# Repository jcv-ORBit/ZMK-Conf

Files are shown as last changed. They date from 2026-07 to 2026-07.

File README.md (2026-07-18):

# ORBit — capacitive-touch trackball bar · Build Guide (v7 / cap-touch)

Low bar trackball on the XIAO nRF52840 **Sense Plus** + PMW3610 stack.
Bearing cup, magnet scroll ring, haptics, and — new in this revision —
**capacitive touch buttons (CAP1188)** replacing every mechanical switch.
Footprint: 135.2 × 34.7 mm, unchanged. This README supersedes the v6 one;
the "Vessel — Build & Wiring Guide" artifact remains valid for assembly
steps A–C and E–H (its section D "Switches" is obsolete, see §4 here).

## What changed in the cap-touch revision

1. **All 6 micro-switches, the floor pockets, and the carrier bridge are
   GONE.** Buttons are now touch zones on the shell, sensed by a CAP1188
   8-channel module on the same I²C bus as the DRV2605L haptics.
2. **New tray: `ORBit_bottom_tray_captouch.3mf`** (drop-in — same walls,
   towers, cup, collar, battery bay, XIAO rails, LRA slot, hall towers):
   - switch pockets and carrier ledges removed; right floor is now a
     **CAP1188 bay**: 40.6 × 18.6 mm cavity (fits a 40 × 18 × 4 module),
     x 22.0–62.6, y ±9.3, 3 mm retaining fence, recessed 1.1 mm into the
     east wall, finger gaps mid-span for removal, wire notch at the west
     end pointing at the DRV/XIAO, two 0.6 mm ribs so solder joints
     don't rock the board.
   - the EC11 recess ribs (gear-route leftovers) are also deleted.
3. **Obsolete files** (keep for reference or delete):
   `ORBit_switch_carrier_left.3mf`, old `ORBit_bottom_tray.3mf`.
4. **Haptic click is now core, not optional.** With no mechanical
   tactility, the DRV2605L fires a click effect on every touch event.
5. **Audio is now provisioned** (piezo, or MAX98357A I²S amp + micro
   speaker on the free EXT pads) so the hardware is ready for the Phase-2
   voice assistant with no respin. See §1 BOM, §3 pin map, §5.6 roadmap.

### Why the device height is unchanged
The ball height is locked by PMW3610 optics — ball bottom ≈ z11 over the
lens at ≈ z9.2. The 6 mm 602040 cell sits floor (z2) to z8, well **under
the z16.2 wall rim**, as do the audio mounts (top z ≈ 9) and CAP bay — all
inside the existing envelope. Any real *slimming* (~2 mm) would come from
the tray-wall / shell-skirt overlap, but the shell, sleeve, ring, and
crown are a dialed-in mated set — a coordinated shell-source pass, not a
tray change.

---

## 1. Sourcing BOM (current build)

### Electronics
- **Seeed XIAO nRF52840 Sense Plus** ×2 (one device, one 2.4 G dongle)
- **PMW3610 breakout + lens** ×1 — mounts to `ORBit_sensor_sled`
- **CAP1188 8-key capacitive touch module** (~40 × 18 × 4 mm) ×1 — NEW
- **DRV2605L haptic driver** ×1 + **coin LRA** ×1 (LRA slot under XIAO)
- **Hall latches ×2** (scroll ring quadrature). TLE4946-2L or any
  **bipolar hall-effect LATCH** in a TO-92-style leaded package that
  runs at 3.3 V — easy subs: Honeywell **SS460S**, Allegro **A1221LUA**;
  TI **DRV5012** if you're OK with SMD (lowest power). Must be a
  *latch* (flips on alternating N/S), NOT a unipolar/omnipolar switch.
  Open-collector/open-drain outputs need the 10 kΩ pull-ups to 3V3
  (§ assembly artifact, step C).
- **Ø3×2 N52 discs** ×12 (ring) + ×8 (shell mount, 4 pairs)
- **LiPo NST 602040, 450 mAh / 1.67 Wh, 3.7 V** ×1 (on hand, **protected**)
  — 6 × 20 × 40 mm; the `_audio` tray pocket is sized for it. The chosen
  cell: already has its protection board (no add-on, no live-cell
  soldering), standard 3.7 V so the XIAO charges it **fully** at 4.2 V,
  1.5× the original runtime, and only 6 mm thick so it clears the rim with
  room to spare while adding moderate heft. *(Alternatives that also fit:
  TW312540 300 mAh thin cell; or the 122134 1000 mAh HV brute — but that
  one is unprotected + HV, so it needs an added PCM and only partly
  charges.)*
- **Slide switch** SS-13D07 ×1 — hard battery disconnect (shipping/storage/
  failsafe), inline on B+. Day-to-day power is IMU wake + soft-sleep;
  you'll rarely touch it. Shelf retained in the tray.
- **25 mm trackball** · **MR63ZZ bearings** ×3 + 3 mm filament axles
- Copper foil tape (~10 mm wide) + 30 AWG wire — touch electrodes
- **SK6812MINI-E addressable LEDs ×16** (+ spares; buy a strip/bag):
  6–8 halo ring + 6 zone windows + 2 slider — SK6812 runs on battery
  voltage, unlike 5 V WS2812. Plus `ORBit_led_diffuser`; translucent
  **smoke TPU** for the sleeve (it is the diffuser for all windows)

### Audio (voice feedback / chimes — provisions the assistant phasing)
Two tiers; wire whichever you want now — both fit existing void space, **no
new 3D files**. See §5.6 for what firmware drives them.
- **Tier 1 — piezo transducer** (chimes/alerts only): a Ø20–27 mm bare
  piezo disc, 0.5 mm thick (e.g. **CUI CPT-2065** or any Ø27 element).
  One PWM pin, no amp. Bonds flat to the shell roof interior; the shell
  becomes the diaphragm and radiates through the glow slots + seams.
- **Tier 2 — real voice** (recommended for the assistant): **MAX98357A**
  I²S DAC+class-D amp breakout (~16 × 13 mm) + one **8 Ω micro speaker**
  (15 mm round, ~4 mm thick — **CUI CMS-15113** / **PUI AS01508AO-3-R**;
  or an 11 × 15 mm rectangular cellphone speaker). The nRF52840 has **no
  DAC**, so this amp (or the piezo) is mandatory for any sound.
  - Wire both if unsure: the MAX98357A path supersedes the piezo. You can
    populate Tier 2 later and leave the pins unused until Phase-2 firmware.

### Fasteners
- M2×8 self-tapping ×2 (sled → posts) · M2×5 self-tapping ×4 (PMW3610 → sled)

## 2. Print plan
PETG, 0.2 mm layers. Parts: `ORBit_bottom_tray_captouch_audio`,
`ORBit_top_shell_captouch_glow`, `ORBit_sensor_sled`, `ORBit_crown` (redesigned),
`ORBit_scroll_ring_magnet`, `ORBit_base_skate`, `ORBit_tpu_top_sleeve` (TPU),
`ORBit_tpu_pad` (TPU), dongle case, tilt wedges/sidecar as desired.
Tray upright with paint-on supports only inside the sensor bay; shell
top-face-down on textured PEI; the CAP bay prints support-free (the 1.1 mm
wall recess bridges).

## 3. Wiring (XIAO Sense Plus — updated pin map)

| Pin | Net | Connect to |
|---|---|---|
| D0 | TOUCH_INT | CAP1188 ALERT/INT (was BTN_M1) |
| D1 | TOUCH_RST | CAP1188 RESET — optional, else tie high (was BTN_M2) |
| D2 / D3 | SCROLL_A/B | hall latch 1 / 2 OUT |
| D4 / D5 | SDA / SCL | **shared I²C bus: DRV2605L + CAP1188** |
| D6 | LED_DIN | SK6812 DIN (330–470 Ω in series) |
| D7–D10 | MOT / SCK / nCS / SDIO | PMW3610 (3-wire SPI) |
| 3V3 / GND | rails | PMW3610, DRV (+EN), CAP1188, halls, amp, pull-ups |
| B+ / B− | LiPo | slide switch inline on B+ (or EXT6 soft-off) |
| CS1–CS8 | touch zones | 30 AWG from CAP1188 to copper-foil electrodes |
| EXT1 | I2S_BCLK | MAX98357A BCLK (Tier-2 audio) |
| EXT2 | I2S_LRC | MAX98357A LRC / word-select |
| EXT3 | I2S_DIN | MAX98357A DIN |
| EXT4 | AMP_SD | MAX98357A SD (mute / power-save; tie high if unused) |
| —or— EXT1 | PIEZO | Tier-1 piezo (single PWM pin; other leg → GND) |

All D0–D10 through-holes are full; **audio lives on the 9 free EXT
castellated pads** (freed when the switch wiring was deleted). I²C
addresses don't collide (DRV2605L 0x5A, CAP1188 0x29 default). The
MAX98357A takes 3V3 (works to ~2.5 V, fine on battery); OUT± → 8 Ω
speaker. GAIN pin sets level — leave floating for 9 dB or strap per its
datasheet.

### Electrode layout (under the shell roof / button caps)
Cut ~10 × 14 mm copper foil pads, stick to the underside of each shell
button cap (the flexure caps stay — they're now cosmetic touch landmarks),
solder a 30 AWG lead to each, route down to the CAP1188 bay. Keep pads
≥4 mm apart. Suggested map: CS1 left-click · CS2 right-click · CS3 middle
· CS4 back · CS5 forward · CS6 push-to-talk · **CS7+CS8 swipe strip**
along the front roof edge (two elongated pads, interpolate for a slider)
— or gang CS7+CS8 as a proximity antenna (see §5).

## 4. Assembly deltas vs the Vessel artifact guide
Follow the artifact steps A–C and E–H unchanged. Replace step D with:
1. Drop the CAP1188 into the right-floor bay (fence retains it; ribs
   under the board). Wires exit the west notch toward the XIAO.
2. Foil electrodes on the shell (above), leads with ~20 mm slack so the
   shell still pops off.
3. Set touch sensitivity after closing up — the stack is shell (1.2 mm)
   + TPU sleeve; CAP1188 gain has plenty of range for that, tune
   SENSITIVITY and averaging registers with the sleeve fitted.

## 5. Firmware
### 5.1 Base (ZMK on nRF52840) — Phase 1
- Base: ZMK + community PMW3610 module; halls = quadrature encoder
  (`alps,ec11`, A/B on D2/D3, `steps = 6`).
- Touch: Zephyr ships a Microchip CAP12xx input driver — bind it on the
  I²C bus with INT on D0 and map 8 inputs to mouse buttons / behaviors
  (small devicetree + listener shim in ZMK).
- **Haptic click**: on any CS press event, fire DRV2605L effect 1
  (strong click); use a sharper/lighter effect per zone so left, right,
  and PTT each *feel* different. Fire on press, not release, <10 ms.
- PTT / talk-to-text: hold CS6 → send the OS dictation hotkey (easy
  path); onboard PDM mic streaming over USB/BLE audio is the advanced
  custom-firmware path.
- Wake: IMU wake-on-motion interrupt from soft-off + CAP1188 proximity
  wake (it can run in a low-power cycled mode and interrupt on approach).

### BLE profiles, pairing, device switching
- ZMK keeps **5 BLE profiles** and auto-reconnects to the last active one
  on wake (IMU wake-on-motion → reconnect in ~1–2 s; approach-glow masks it).
- **Switch hosts**: bind `&bt BT_SEL n` / `BT_NXT` to a combo —
  recommended gesture: *touch-hold the slider (CS7/8) + spin the crown*;
  each detent steps a profile, halo blinks the profile number in amber,
  haptic tick per step.
- **Pair a new device**: select an empty profile — the device advertises
  automatically and appears in the host's Bluetooth list. Long-hold the
  same gesture = `&bt BT_CLR` (forget current profile).
- **Dongle** (2nd XIAO): a BLE→USB HID receiver for hosts with no/locked
  Bluetooth or for lowest latency. It is optional and is NOT storage —
  it enumerates as a plain USB mouse. It occupies one of the 5 profiles;
  moving the dongle between machines is itself a host-switching story.

### Ambient glow architecture (dark slate / copper-bronze accent)
Goal: soft warm amber (logo palette) halo around the ball, a dot per
touch zone, and a light-line along the slider. Subtle, breathe-on-approach,
off in sleep.
- **Driver**: preferred = the existing D6 addressable chain — use
  **SK6812MINI** (happy at 3.3–3.7 V on battery, unlike 5 V WS2812):
  6–8 LEDs in a ring under the aperture boss + 1 under each button
  window + 2 under the slider pinstripe ≈ 10–12 LEDs, one pin, exact
  copper-amber set in firmware. Alternative: the CAP1188 has 8 LED
  driver pins with hardware touch-linking and breathe/pulse behaviors
  (zero firmware) — but only if your module breaks LED1–8 out; most
  generic ones don't. Check the header before counting on it.
- **Ball halo needs no cutting**: light fired upward under the aperture
  boss leaks through the existing shell-aperture / ring-skirt shadow gap.
- **Button + slider windows — CUT, in `ORBit_top_shell_captouch_glow.3mf`**:
  0.8 mm through-slots at |y| = 13.9 (a third "light seam" running just
  outboard of the twin pinstripes). Zone windows (6 mm long) on one roof
  edge at x = **−38, −27** (back / fwd), **25** (PTT), **44, 52, 60**
  (L / M / R click); an 18 mm **slider window at x 41–59** on the
  opposite edge, directly above the CAP1188 bay. The windows *define*
  the touch zones — stick each foil electrode under the roof beside its
  window, LED under the slot. The six switch **stems are deleted** from
  this shell (nothing to press anymore); the flexure caps and hinges are
  kept as tactile landmarks. Sleeve stays **uncut** — print it in
  translucent smoke TPU: sealed against dust, diffuses the glow,
  invisible until lit.
- **HiLetgo module L1–L8 pins**: use them on the bench (hardware
  touch-linking while tuning sensitivity), not in the final glow — the
  SK6812 chain does color, blink-counts, and animations that the L-pins
  can't.
- **Power**: amber at low duty, breathing only on proximity/touch, all
  off in soft-sleep — negligible against the 300 mAh cell with
  wake-on-motion.

### Audio placement — integral mounts in the `_audio` tray
The tray carries the Tier-2 audio mounts over the CAP1188 bay (the only
place with vertical void):
- **MAX98357A amp**: recessed shelf over the CAP bay's **west/inner end**
  (x 22.5–35, seat z 5.8), non-magnetic so its nearness to the hall
  towers is harmless. Wires drop out the open east side to the CAP bundle.
- **Speaker**: an up-firing corral over the CAP bay's **east end**
  (x 45–59, seat z 5.6), aimed at the 18 mm slider glow window as its
  acoustic port (through the smoke TPU). Placed as far from the scroll
  **hall latches** as the bay allows — nearest-corner gap ≈ 13 mm.
  ⚠ A speaker has a magnet: if you see phantom scroll, that coupling is
  why — add a thin steel shield washer behind the speaker, or shift it
  east a few mm. Use the **thin 11 × 15 × 3.5 mm** rectangular speaker
  here (fits the corral and the roof); a 15 mm round also drops in.
- **Assembly order**: wire the CAP1188 first, then set the amp and speaker
  into their mounts (they sit just above the module). Dry-fit before
  bonding.
- **Piezo alternative** (Tier 1): skip both mounts, bond a Ø27 disc to the
  shell roof — sound exits the glow slots. One PWM pin, no amp.
- **Power**: chimes are free; class-D voice is bursty (100s of mA peaks) —
  the 1000 mAh cell handles short prompts easily, not continuous playback.

### Onboard storage ("carry your config")
- The XIAO nRF52840 has **2 MB QSPI flash**; TinyUSB MSC can expose it
  as a small USB drive over USB-C (wired only — BLE cannot serve files).
- Recommended product shape: **the device carries its own keymap/macros/
  settings as editable text files** — plug into any machine, tweak, done,
  no companion app. Do NOT pitch it as a file-shuttle: 2 MB is tiny, and
  a pointing device that also enumerates as removable storage pattern-
  matches BadUSB to corporate IT. Gigabyte storage would need a microSD
  on spare EXT pads (SPI) — judged overdesign; skip.

### 5.6 Firmware roadmap — the adaptation assistant (phasing)
The hardware above is fully provisioned for a voice + haptic "device
adaptation assistant." Build it in phases so the firmware ambition never
blocks the physical product — the same PCB stack runs all three.

**Phase 1 — ship on ZMK (now).** §5.1–§5 above: pointer, touch buttons,
haptic click, glow, per-profile BLE switching, IMU wake. A real, usable
trackball today. Validate the object.

**Phase 2 — custom Zephyr assistant.** ZMK *is* Zephyr underneath; drop to
raw Zephyr when the assistant features need audio + custom BLE + sensor
fusion (ZMK's abstractions fight all three). Buildable, genuinely
distinctive:
- **Voice feedback = pre-rendered clip library in the 2 MB QSPI flash**,
  played over I²S (Tier-2 amp). A finite prompt set ("switched to
  laptop," "precision on," "hold to talk") — how earbuds/cameras do voice.
  The nRF **cannot** synthesize arbitrary speech on-device; arbitrary TTS
  is a host job (host renders → streams over **USB Audio Class**, which
  also carries the PDM mic → the puck becomes a little speakerphone).
- **Personalization = an adaptive rules/stats engine, not an LLM.** Counters,
  timers, per-app config recall — deterministic, tiny, debuggable. "Learns
  your favorite config per host and announces the switch (voice + haptic +
  glow)" is the shippable core.
- **TinyML where it earns it:** two small models only — keyword spotting
  (a few voice commands) and IMU **gesture** classification. TFLite-Micro /
  Edge Impulse territory on the M4F.
- **Device switching by gesture (relative, reliable):** tilt/rotate the
  puck one way → host 1, the other way → host 2. Uses tilt-relative-to-
  gravity; rock-solid with the 6-axis IMU.

**Phase 3 — research spikes (defer).**
- **True spatial "point at the device" switching** is NOT possible with the
  6-axis IMU: accel gives tilt-vs-gravity, gyro drifts, and there's **no
  magnetometer** for absolute heading. It needs a 9-axis board (+ calibration
  ritual) or BLE AoA silicon (nRF5340-class). Use relative gesture switching
  (Phase 2) until/unless a 9-axis respin happens.
- On-device behavioral "AI" beyond the rules engine → host/cloud, not the M4F.

## 6. Feature roadmap ("over the edge" list, all zero/near-zero BOM)
1. **Solid-state buttons + per-zone haptic click** — the headline. No
   switch wear, sealed top, tunable feel.
2. **Swipe strip** (spare CS7/CS8): horizontal scroll, volume, or tab
   switcher. A trackball with a touch slider is a genuine differentiator.
3. **Approach glow + ambient accent lighting**: proximity mode + the
   amber glow architecture above — halo, zone dots, slider line breathe
   before your hand lands; radio wakes at the same moment (hides BLE
   reconnect latency).
4. **Precision / jog mode**: touch-hold a zone while rolling the ball →
   CPI drops 4×; hold + ring spin = per-app jog dial.
5. **PTT / talk-to-text** via onboard mic (CS6 zone) — already planned.
6. **IMU gestures**: wake-on-motion (planned), lift-to-lock (cursor
   freezes when you reposition the unit), tilt-to-switch hosts,
   double-tap the shell as a hidden button.
7. **Voice + haptic assistant** (Phase 2, §5.6): announced host switches,
   spoken onboarding/coaching from a clip library, keyword commands.
8. Deliberately *not* included: touch typing zones, RGB theatrics,
   displays, on-device TTS, absolute spatial awareness — they'd dilute the
   "quiet desk object" identity or over-reach the M4F/6-axis hardware.

## 7. File manifest (current)
| File | Status |
|---|---|
| `ORBit_bottom_tray_captouch_audio.3mf` | **CURRENT tray** — cap-touch + 602040 (450 mAh protected) battery pocket + integral amp/speaker mounts |
| `ORBit_bottom_tray_captouch.3mf` | superseded (cap-touch, old 300 mAh bay, no audio mounts) |
| `ORBit_bottom_tray.3mf` | superseded (switch version) |
| `ORBit_top_shell_captouch_glow.3mf` | **current shell** — glow windows cut, switch stems removed |
| `ORBit_top_shell_detailed.3mf` | ⚠ DO NOT SLICE — contains 7 stacked copies plus a misplaced collar chimney and a solid Ø22 plug at the origin (WIP leftovers) that would block the ball bore |
| `ORBit_tpu_top_sleeve.stl` / `ORBit_crown.stl` | current finish parts |
| `ORBit_scroll_ring_magnet` / `ORBit_sensor_sled` / `ORBit_base_skate` | unchanged |
| `ORBit_switch_carrier_left.3mf` | **obsolete** |
| `ORBit_all_files.3mf` | re-plate: swap in the captouch tray, drop the carrier |
| dongle case, LED diffuser, tilt wedges, sidecar, TPU pad | unchanged |

**Audio needs no 3D files** — piezo bonds to the shell roof; Tier-2
speaker + MAX98357A occupy existing void (§ Audio placement). Both are
retrofittable at any time.

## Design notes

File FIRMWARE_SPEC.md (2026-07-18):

# ORBit Firmware Specification — rev A (2026-07-17)

Handoff spec for firmware development on the ORBit capacitive-touch trackball bar.
Hardware and geometry are FROZEN at this revision. The wiring section of the project
README (v7 cap-touch) is authoritative for harness details; this file is authoritative
for firmware scope and contracts.

## 1. Device summary

Low-profile wireless trackball bar, 135.2 × 34.7 × ~19 mm (138 × 37.5 with TPU sleeve),
XIAO nRF52840 Sense Plus. No moving switches: optical trackball, magnetic scroll ring
(hall quadrature), 6 capacitive touch zones, 2-pad capacitive slider. Outputs: 8-LED
amber glow chain, LRA haptics, I2S speaker. Identity: quiet dark desk object — amber
light only, subtle haptics, sound opt-in. Every feature must work with the sleeve fitted.

## 2. Platform + pin map (authoritative)

| Pin | Net | Device |
|---|---|---|
| D0 | TOUCH_INT | CAP1188 ALERT |
| D1 | TOUCH_RST | CAP1188 RESET (or tie high) |
| D2 / D3 | SCROLL_A/B | hall latches SS460S (quadrature, 10k pull-ups to 3V3 on harness) |
| D4 / D5 | SDA / SCL | shared I2C: CAP1188 @0x29, DRV2605L @0x5A |
| D6 | LED_DIN | SK6812MINI-E chain ×8 (330–470 Ω series; battery-voltage strip, 3.3 V logic OK) |
| D7 | MOT | PMW3610 motion IRQ |
| D8 / D9 / D10 | SCK / nCS / SDIO | PMW3610 3-wire SPI (park MISO on unused pin; reads on SDIO) |
| EXT1 / EXT2 / EXT3 | I2S BCLK / LRC / DIN | MAX98357A |
| EXT4 | AMP_SD | MAX98357A shutdown (drive low when idle) |
| B+ / B− | LiPo 602040 450 mAh protected | hard slide switch inline on B+ |

Sensor board: randware/siderakb PMW3610 breakout (23.5 x 31.5 x 1.6, optical center =
board center, M3 holes on a 17.5 x 25.5 grid). Mounted component-side down on the v2
sled; lens reference plane at device z8.6, Z = 2.4 mm to the ball (datasheet 2.2-2.6).

Onboard (XIAO Sense): LSM6DS3TR-C 6-axis IMU (internal I2C, wake-on-motion), PDM mic,
2 MB QSPI flash (P25Q16H), USB-C, LiPo charger (4.2 V). No DAC (all audio via I2S amp).
No magnetometer (tilt-relative gestures only; absolute heading impossible).

## 3. Physical → firmware map

Coordinates: device mm; x −67.6 (west/USB) … +67.6 (east); y −17.35 (front, glow-dot
edge) … +17.35 (rear, slider edge).

| Surface | Physical | Firmware contract |
|---|---|---|
| Trackball | Ø25 ball at z11, PMW3610 lens ref plane z8.6 (Z=2.4 to ball, datasheet 2.2–2.6) | REL X/Y, CPI 600 default; set swap/invert flags at bring-up (board mounts component-side down, long axis = device x) |
| Crown | Ø33.8 ring, 12 alternating magnets, halls at (6.2,14.35)/(11.75,14.35) | quadrature 24 edges/rev; continuous scroll |
| Touch zones | foil electrodes under shell caps; finger stack = 1.0 mm TPU + 1.2 mm shell | CS1 L-click (x38.6–50) · CS2 R-click (x51.5–65 rear) · CS3 M-click (x51.5–65 front) · CS4 back (−48…−28) · CS5 fwd (−26…−8) · CS6 PTT (25.7–37). Act on press <10 ms with haptic |
| Slider | CS7+CS8 elongated pads, rear edge x41–59 | v1: half-strip taps (vol/scroll, both=mute); v2: interpolated absolute position |
| Glow | 8× SK6812 in shell pockets w/ funnels → sleeve lenses | index 0–5 = zone dots WEST→EAST (positionally over CS4,CS5,CS6,CS1,CS3,CS2), 6–7 = slider (x45.5/54.5). Amber #FFB457 family ONLY; ≤30% on battery; off in sleep |
| Haptics | LRA Ø10×4 at (−52,0), DRV2605L | per-zone effect identity: sharp click L/R, soft tick back/fwd, double-tick PTT, micro-tick per scroll/profile step. Run LRA auto-cal once, persist |
| Speaker | 15×11 8Ω 0.7W in deck (50.5,−6.5), floor vent | I2S 16-bit mono clips from QSPI; chimes ≤1 s, prompts ≤3 s; AMP_SD low when idle |
| USB | port high on west wall through sleeve window | charge + HID; later MSC/CDC/UAC composite |
| IMU | west end, board component-side down | wake-on-motion = sleep exit; lift-to-lock; double-tap; tilt-hold gestures |

Hardware gotchas that masquerade as firmware bugs:
- Speaker magnet is 15.3 mm from nearest hall latch → phantom scroll during audio = magnetic coupling (hardware fix), not code.
- Cap-sense MUST be tuned with the TPU sleeve fitted (dielectric stack roughly halves raw counts vs bare bench).

## 4. v1 launch firmware (ZMK) — current state and work package

Repo seed: `zmk-config/` — shield `vessel` on `seeeduino_xiao_ble`, GitHub Actions build,
badjeff `zmk-pmw3610-driver` module. Working: PMW3610 pointer (SPI1, MOT D7, CPI 600),
halls as `alps,ec11` steps=24 (bound to volume as placeholder), deep sleep 30 min, BLE +8 dBm.

**CRITICAL: the config predates the cap-touch pivot.** D0/D1 are still direct-GPIO buttons
(`kscan_direct` + 2-key keymap). The v1 work package:

1. Delete `kscan_direct` and the 2-key keymap (D0/D1 now belong to CAP1188).
2. Bring up CAP1188: Zephyr `microchip,cap12xx` input driver on I2C0 @0x29, INT on D0;
   thin listener mapping press/release → ZMK behaviors. Fallback if the driver fights
   ZMK's input pipeline: small custom module (ALERT pin + status registers).
3. Zone map per §3 (CS1→LCLK … CS6→PTT-as-dictation-hotkey-hold).
4. Slider v1: CS7=scroll-left/vol-down, CS8=scroll-right/vol-up, both=mute.
5. Haptic module (no ZMK driver exists): DRV2605L init + auto-cal at boot (persist),
   library effect per CS press; touch→haptic <10 ms.
6. Glow v1 on D6 (`worldsemi,ws2812-spi` compatible works for SK6812): amber idle low
   duty, zone flash on touch, breathe on proximity wake, all-off in sleep. No animations.
7. Wake: IMU wake-on-motion + CAP1188 standby-cycled proximity; glow breathe masks BLE
   reconnect (1–2 s).
8. Profiles: ZMK 5-profile BLE; gesture = touch-hold slider + crown spin steps profiles
   (haptic tick per step, LED0–4 blink index); long-hold = BT_CLR.
9. Rebind crown to true wheel scroll (`&msc`); slider owns volume.
10. Stretch: `vessel_dongle` shield (2nd XIAO as BLE-central→USB-HID bridge).

**v1 definition of done:** pair to two hosts + gesture-switch between them; ball/ring/
6 zones/slider all functional with per-zone haptics; approach glow; soft-sleep <50 µA
target, active <5 mA avg with glow at duty (30-day standby on 450 mAh); survives sleeve
on/off without retune (auto-recal on wake).

## 5. Phase 2 — custom Zephyr (product vision)

Drop from ZMK to raw Zephyr when audio + custom BLE + sensor fusion are in scope.
Architecture: input service (PMW3610/CAP/halls/IMU) → interaction engine (gestures,
slider interpolation, chords) → deterministic policy/rules engine (per-host+per-app
profiles, counters — NOT an LLM) → outputs (glow scenes, haptic grammar, I2S clip
player) + transports (BLE HID+BAS+custom ORBit GATT config service; USB composite
HID+MSC+CDC, later UAC; littlefs on QSPI).

Commitments: continuous slider w/ LED position feedback; precision mode (hold zone →
CPI÷4) and jog (hold + crown); voice clip library in QSPI (nRF cannot TTS — arbitrary
speech is host-rendered over USB Audio when docked); consistent haptic vocabulary;
IMU lift-to-lock / double-tap / tilt-hold host switch; config-as-files over opt-in USB
MSC (hold CS6 while plugging — BadUSB-perception mitigation); ORBit GATT service
mirroring config; TinyML capped at exactly two models (PDM keyword spotting, IMU
gesture classification; TFLite-Micro).

## 6. Phase 3+ / adjacent

- Mission deck: powered SBC dock (Pi Zero 2 W class) scripting the device over USB
  composite + versioned CDC command channel — keep descriptors clean now.
- DFU: stock UF2 (double-tap reset) for v1 → MCUboot signed BLE DFU in Phase 2
  (sleeve-off access must never be required for updates).
- Absolute "point-at-machine" switching: impossible on 6-axis (no heading ref) — needs
  9-axis respin or BLE AoA. Deferred; tilt-relative covers it.
- Battery: voltage-curve fuel gauge → BLE BAS + crown-hold charge meter on LED0–5.
- Manufacturing test mode: hidden build target exercising every subsystem (LED walk,
  haptic sweep, tone, sensor dumps over CDC). Build it in Phase 1.

## 7. Working agreements

- Bring-up order (hardware-risk order): pointer direction → ring steps → CAP sensitivity
  (sleeve fitted) → haptic autocal → glow chain → sleep/wake → profiles → audio.
- Keep the ZMK shield for v1; Phase 2 lives in a sibling Zephyr app sharing devicetree
  fragments.
- Identity guardrails: amber-family light only, no RGB theatrics; subtle haptics; sound
  off by default; every feature works sleeve-on.
- The CAD is parametric Python — if firmware needs a physical change (LED position,
  access hole), it is a one-line edit and a reprint. Ask; don't work around.

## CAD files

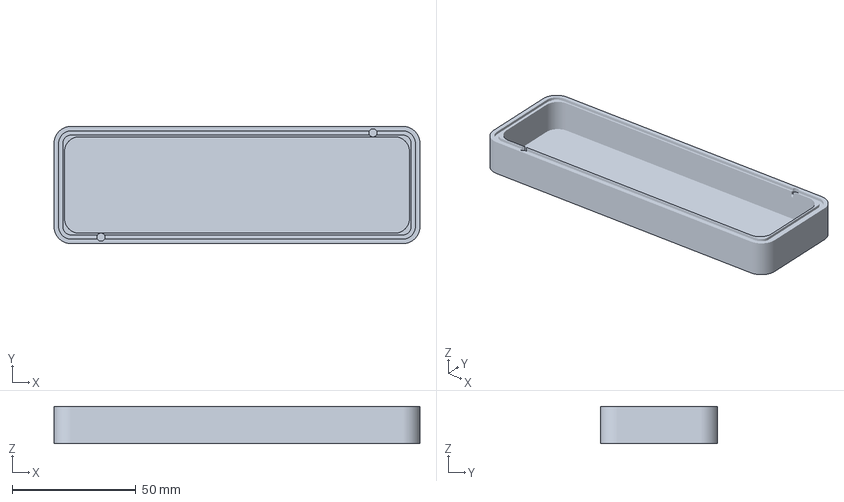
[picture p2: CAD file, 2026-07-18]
ORBit_case_lid.3mf
148.0 x 47.5 x 15.0 mm

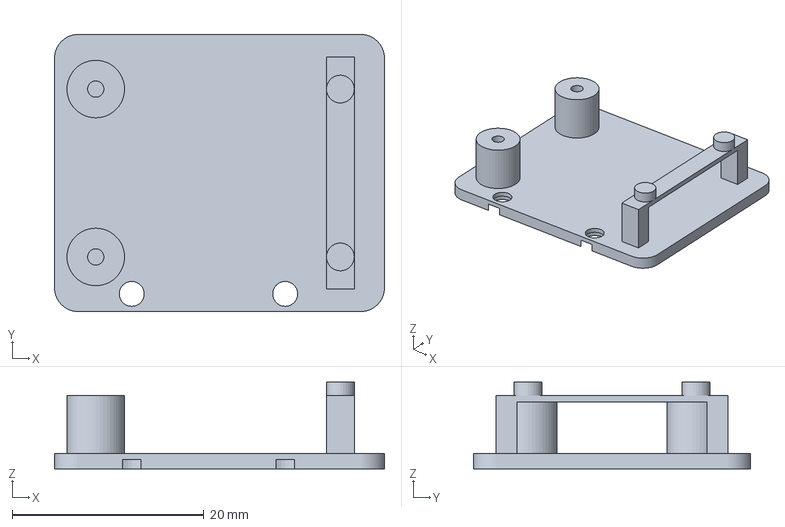
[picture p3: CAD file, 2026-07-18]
ORBit_sensor_sled_v2_pmw.3mf
34.4 x 28.9 x 9.05 mm

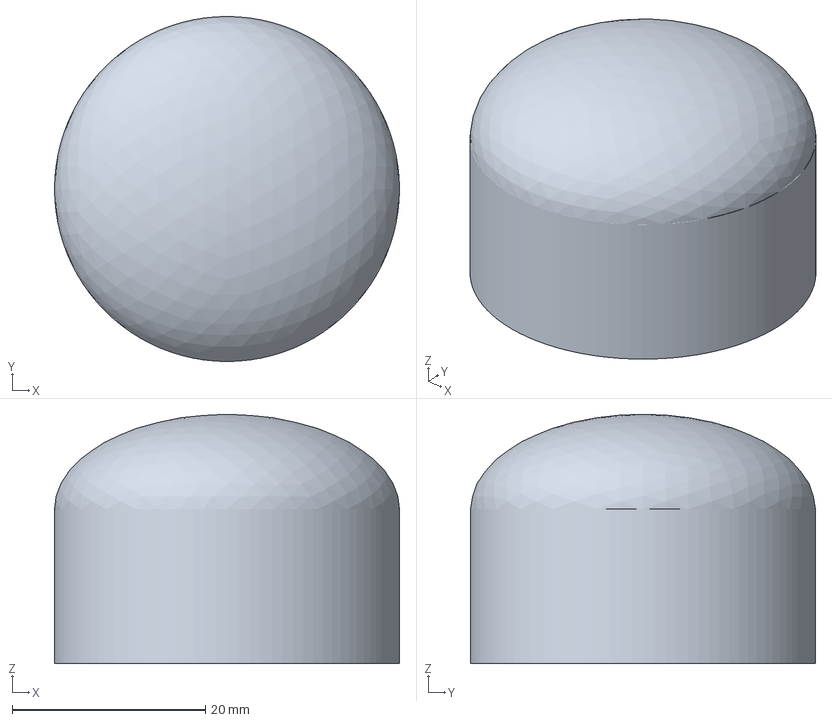
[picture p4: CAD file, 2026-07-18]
ORBit_ball_garage.3mf
35.7 x 35.7 x 25.8 mm

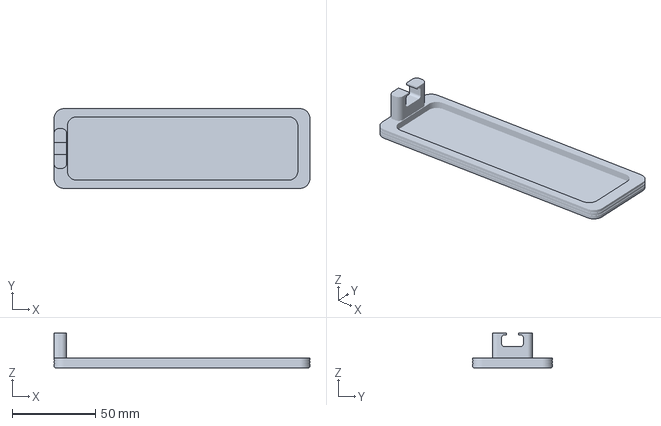
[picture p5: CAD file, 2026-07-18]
ORBit_launch_pad.3mf
154.0 x 48.0 x 21.0 mm

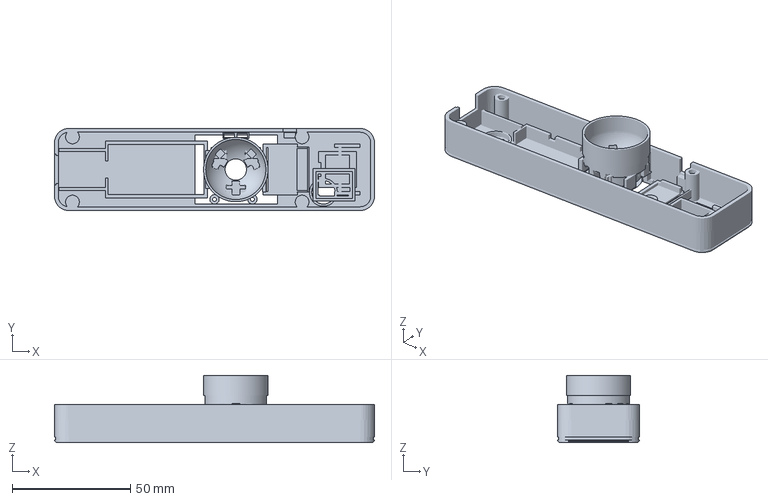
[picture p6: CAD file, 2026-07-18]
ORBit_bottom_tray_v4_pmw.3mf
135.2 x 34.7 x 28.4 mm

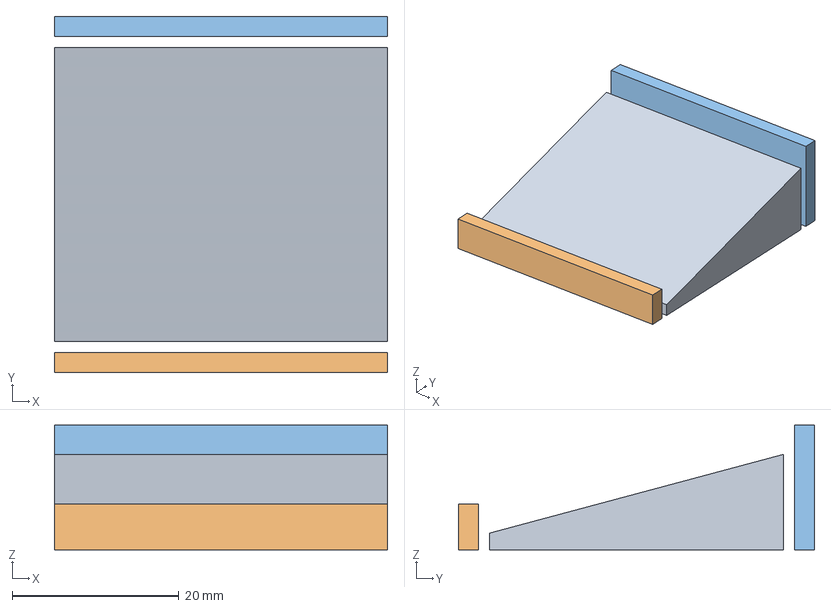
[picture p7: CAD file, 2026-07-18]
ORBit_tilt_wedge_15deg_v2.3mf
40.0 x 42.7 x 15.0 mm

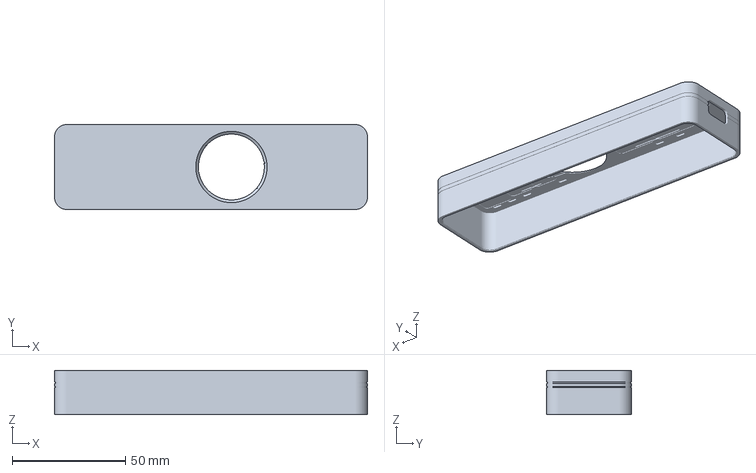
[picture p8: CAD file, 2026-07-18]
ORBit_tpu_top_sleeve_v2.3mf
138.0 x 37.5 x 19.4 mm

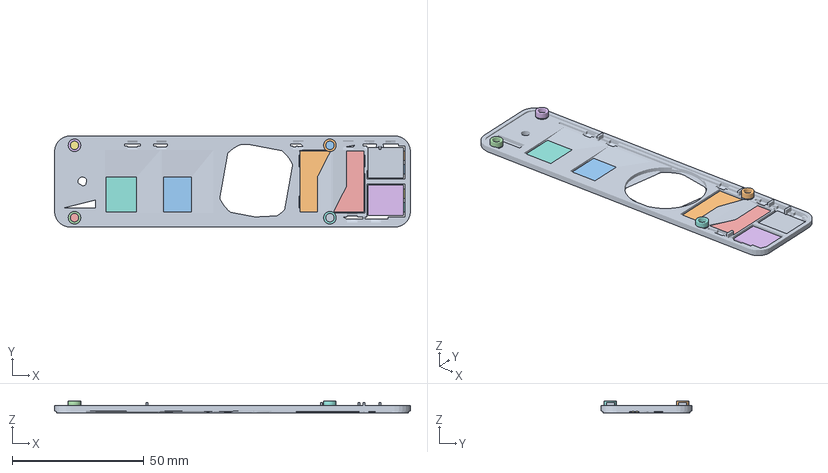
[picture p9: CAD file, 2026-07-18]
ORBit_top_shell_v3_x2d.3mf
135.2 x 34.7 x 4.60 mm
shell_main_v3

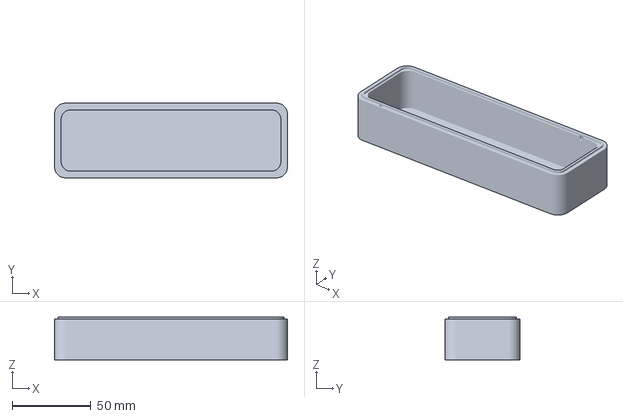
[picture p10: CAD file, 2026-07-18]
ORBit_case_base.3mf
148.0 x 47.5 x 27.2 mm

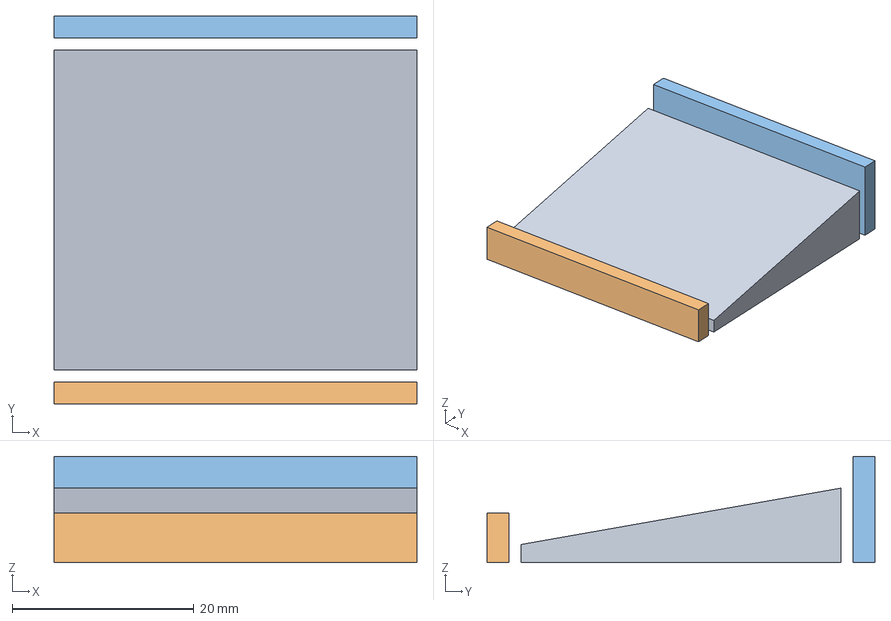
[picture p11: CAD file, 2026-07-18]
ORBit_tilt_wedge_10deg_v2.3mf
40.0 x 42.7 x 11.7 mm

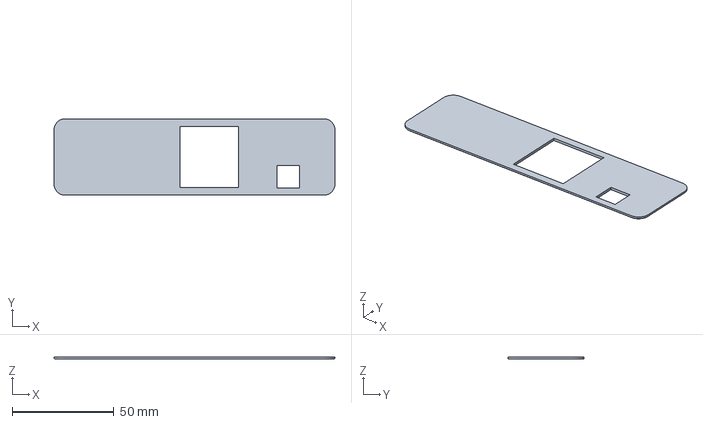
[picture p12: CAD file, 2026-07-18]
ORBit_base_skate_v2.3mf
138.0 x 37.5 x 1.20 mm

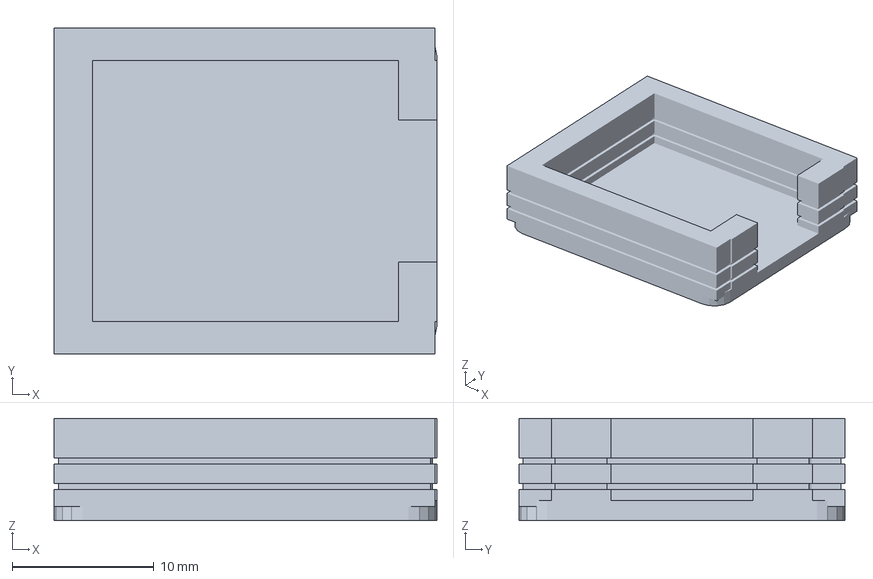
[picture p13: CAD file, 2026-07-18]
ORBit_dongle_case_base_v2.3mf
27.0 x 23.0 x 7.20 mm

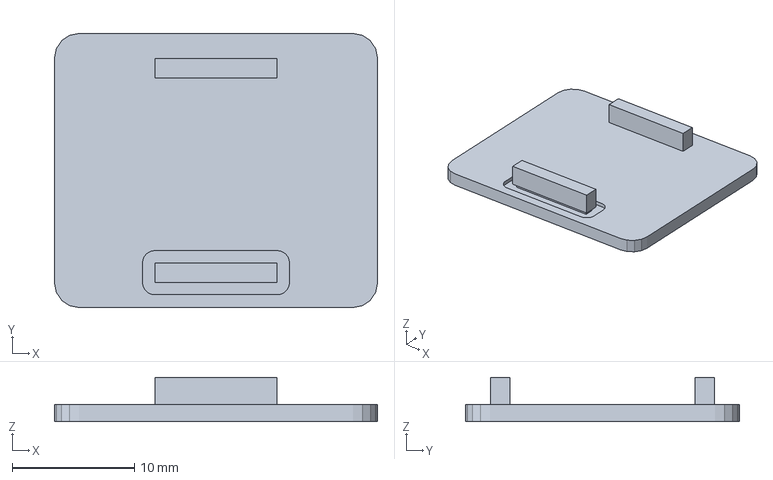
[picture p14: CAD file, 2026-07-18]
ORBit_dongle_case_lid_v2.3mf
26.4 x 22.4 x 3.60 mm

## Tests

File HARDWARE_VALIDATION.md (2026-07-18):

# ORBit — Hardware Validation Checklist

Every value in the v1 firmware that can only be confirmed on the physical device
lands here, with the **exact expected behavior** and **how to adjust** it. The
firmware ships a best-documented default plus a marked tuning point (Kconfig
option or devicetree property) for each; this file is where a human closes the
loop with hardware in hand.

- **No hardware was in the loop** when this firmware was written. Treat every
  unchecked box as unverified, not as broken.
- Tune in **bring-up order** (spec §7, hardware-risk order): pointer direction →
  ring steps → CAP sensitivity (sleeve fitted) → haptic autocal → glow chain →
  sleep/wake → profiles → audio.
- **Cap-sense and glow diffusion must be tuned with the TPU sleeve fitted** — the
  dielectric stack roughly halves raw touch counts vs. a bare bench (spec §3).
- The manufacturing **test mode** build (spec §6: LED walk, haptic sweep, tone,
  sensor dumps over CDC) is the intended harness for running this checklist. It
  is built in Phase 1; see its section below once it lands.

This checklist grows as each work-package PR merges. Items are added by the PR
that introduces the tunable.

---

## Legend
- **Observe** — what to do / watch on the device.
- **Expected** — the pass condition.
- **Tune** — the firmware knob to change if it's wrong, and where it lives.

---

## 1. Trackball pointer direction & CPI  _(seed; PMW3610)_
- [ ] **Observe:** move the ball up/down/left/right; watch the cursor.
- **Expected:** cursor tracks 1:1 in the same direction on all four axes.
- **Tune:** the board mounts **component-side down, long axis = device x**
  (spec §3), so at least one invert/swap is likely needed. Uncomment/adjust in
  `zmk-config/config/boards/shields/vessel/vessel.overlay` on the `trackball`
  node: `swap-xy;`, `invert-x;`, `invert-y;`.
- [ ] **Observe:** general tracking speed/feel at the default **CPI 600**.
- **Expected:** comfortable desktop tracking; no skipping.
- **Tune:** `cpi = <600>;` on the same node (datasheet Z = 2.2–2.6 mm; lens ref
  plane sits at Z = 2.4 to the ball — mechanical, not firmware).
- **Note:** the PMW3610 runs on **SPIM3** (not SPIM1) — SPIM1 and the CAP1188's
  I²C (TWIM1) are the same nRF52840 instance and can't coexist. Same pins
  (D8/D9/D10); if the pointer is dead after the item-2 change, suspect the SPI3
  move first.

## 2. Scroll ring (hall quadrature) step feel  _(seed)_
- [ ] **Observe:** spin the crown; count detents vs. scroll/volume steps.
- **Expected:** smooth, continuous stepping; direction matches spin.
- **Tune:** `steps = <24>;` on the `scroll` (`alps,ec11`) node in the overlay.
  > Note: spec §3/§4 say **24 edges/rev** (authoritative); the project README
  > §5.1 says `steps = 6`. Per precedence the firmware uses 24. If detents feel
  > too coarse/fine on-device, this is the knob. If direction is reversed, swap
  > `a-gpios`/`b-gpios` (D2/D3).

## 3. CAP1188 touch bring-up (sleeve fitted)  _(PR item 2; `microchip,cap12xx`)_
Tune with the **TPU sleeve fitted** — the 1.0 mm TPU + 1.2 mm shell stack roughly
halves raw counts vs. bare bench (spec §3).
- [ ] **Observe:** touch the three click caps. **Expected (item 2 scope):** CS1 =
  left click, CS2 = right click, CS3 = middle click. CS4–CS8 do nothing yet
  (they're `&none` until items 3/4).
- [ ] **Observe:** ALERT/interrupt path — a touch registers promptly (spec target
  <10 ms). **Tune:** `int-gpios` on the `cap1188@29` node (D0, active-low,
  internal pull-up). If nothing registers, check the ALERT pull-up and that
  RESET (D1) is tied high (spec §2).
- [ ] **Observe:** no phantom/adjacent-zone triggers. **Expected:** each cap fires
  only its own zone.
- ⚠️ **KNOWN TUNING GAP — read before bench tuning.** The stock `microchip,cap12xx`
  driver exposes **no sensitivity/gain/threshold devicetree property** (only
  `int-gpios`, `repeat`, `poll-interval-ms`, `input-codes`). It runs the chip's
  **default** sensitivity. So if, with the sleeve on, touches are too weak
  (missed) or too hot (false triggers), there is **no firmware knob** in this
  driver. Options, in order: (a) increase electrode foil area / improve the
  dielectric contact (hardware, spec §7 allows a one-line CAD change); (b) toggle
  `repeat` and `poll-interval-ms`; (c) patch/fork the driver to write the CAP1188
  SENSITIVITY (0x1F) and averaging (0x24) registers at init, exposed as a Kconfig
  option; (d) fall back to the custom module (spec §4.2). Item 2 ships default
  sensitivity; capture the observed behavior here and pick an option if needed.
- [ ] **Observe:** I²C bus health with both devices — CAP1188 @0x29 and (after
  item 5) DRV2605L @0x5A share `&i2c1` (D4/D5). **Expected:** both enumerate; no
  bus lockups.

## 4. Touch zone mapping CS4/CS5/CS6  _(PR item 3)_
- [ ] **Observe:** in a web browser, tap CS4, then CS5.
- **Expected:** CS4 = browser **back**, CS5 = browser **forward** (they send
  mouse buttons 4/5, the standard back/fwd buttons — most OSes/browsers honor
  them out of the box; some Linux setups need `imwheel` or equivalent).
- **Tune:** `bindings` indices 3/4 in `cap_zone_behaviors`
  (`zmk-config/config/vessel.keymap`).
- [ ] **Observe:** hold CS6, speak, release. **Expected:** the host's
  dictation/voice input engages while held. CS6 holds **`C_VOICE_COMMAND`**
  (HID consumer 0xCF — the mic key on modern keyboards) for as long as the
  finger stays on the zone:
  - **macOS:** 0xCF is the dictation key. Default dictation is *tap to start,
    tap again to stop* — a quick tap of CS6 toggles it. For true
    press-and-hold PTT, hold-to-talk dictation tools (or newer macOS
    hold-the-mic-key behavior) use the hold directly.
  - **Windows 11:** 0xCF opens voice typing. **Windows 10 / not honored:**
    swap the binding for the explicit chord `&kp LG(H)` (Win+H).
  - **iOS/Android:** 0xCF summons the assistant (hold = hold-to-talk).
- **Tune:** `bindings` index 5 in `cap_zone_behaviors`. This is inherently
  **per-host** — pick the binding for your primary OS; per-profile PTT
  variants would need a layer/profile-conditional setup (note for item 8).
- [ ] **Observe:** brush a finger across adjacent zones (CS4→CS5, CS1→CS3).
- **Expected:** each zone fires once, no double-fires at boundaries. If zones
  bleed together, revisit §3's sensitivity options (sleeve fitted).

## 5. Slider v1: CS7/CS8 taps + both = mute  _(PR item 4)_
Spec §3: "v1: half-strip taps (vol/scroll, both=mute)". The firmware picks
**volume** (item 9 later gives the crown true wheel scroll and says "slider
owns volume"). Chording is done by the repo-local `orbit,input-processor-chord`
module (`zmk-config/modules/orbit/`) — ZMK combos only work on kscan positions,
not input events, so this is custom code: **bench-test it deliberately.**
- [ ] **Observe:** tap CS7, tap CS8. **Expected:** volume down / volume up, one
  step per tap, arriving up to ~75 ms after the tap (the chord window).
- [ ] **Observe:** hold CS7 or CS8. **Expected:** most hosts auto-repeat a held
  volume key. If yours doesn't, repeat-on-hold needs the cap12xx `repeat`
  property (see §3) — capture behavior here first.
- [ ] **Observe:** press both pads together (flat two-finger tap). **Expected:**
  one **mute** toggle; NO volume step before it. Release and repeat — unmute,
  again no stray volume steps.
- [ ] **Observe:** deliberately sloppy chords (one finger lands ~50–100 ms
  after the other). **Expected:** inside the window = mute; outside = two
  volume steps. If real two-finger taps often land as volume steps, widen the
  window; if single taps feel laggy, narrow it.
- **Tune:** `timeout-ms` on the `slider_chord` node in `vessel.overlay`
  (default 75). It is both the chord window and the worst-case single-tap
  latency — one knob, two effects.
- [ ] **Observe:** rapid alternating taps CS7-CS8-CS7… **Expected:** clean
  volume steps, no missed or stuck events. (The processor's pathological-case
  guarantee: rare degenerate sequences may *miss* a chord, but can never leave
  a key stuck.)

## 6. DRV2605L haptics: LRA auto-cal + per-zone feel  _(PR item 5)_
Playback uses the stock Zephyr `ti,drv2605` driver; boot auto-cal/persist and
the per-zone map are the repo-local `orbit,haptic-feedback` glue
(`zmk-config/modules/orbit/src/haptic_feedback.c`).
- [ ] **Before first power-up:** set `vib-rated-mv` / `vib-overdrive-mv` on the
  `drv2605@5a` node (`vessel.overlay`) from the actual LRA datasheet. Shipped
  defaults (1800/2500 mV) suit a generic Ø10×4 LRA; too high can cook a small
  motor, too low feels mushy.
- [ ] **Observe (first boot only):** ~0.8 s after power-on the LRA buzzes for
  up to ~1 s — that's auto-cal. Log line `LRA auto-cal OK (...) persisted`.
  **Expected:** later boots are silent with `LRA cal restored (...)` instead
  (results persist in settings under `orbit/lracal`).
  - If the log says `auto-cal FAILED` or `timed out`: check LRA wiring; the
    firmware falls back to open-loop drive (weaker but functional). Consider
    setting `lra-drive-time` on the `haptic_feedback` node = LRA half-period
    (`((1000/f_hz)/2 − 0.5)/0.1`, e.g. 24 for 170 Hz) and re-running cal
    (delete the setting or reflash with erased settings partition).
- [ ] **Observe:** touch each zone. **Expected feel** (spec §3 identity —
  effect IDs are the `effects` array on `haptic_feedback`, TI ROM library):
  CS1/CS2 sharp click (4), CS3 lighter click (5), CS4/CS5 soft tick (26),
  CS6 double-tick (10), CS7/CS8 micro-tick (24). Buzz should feel *subtle* —
  identity guardrail, not phone-vibrate.
- [ ] **Observe:** haptic latency — touch-to-buzz should read as instant
  (<10 ms; it fires on raw pad contact, before the slider chord window).
- [ ] **Observe:** single slider tap = exactly ONE tick (not a double ~75 ms
  apart). If doubled, `dedup-ms` (90) has been set below the chord window.
  A two-finger mute chord = two near-simultaneous ticks (one per pad) — this
  is expected v1 behavior.
- [ ] **Observe:** I²C bus health — CAP1188 @0x29 and DRV2605L @0x5A share
  `&i2c1`; hammer zones while rolling the trackball, watch for bus errors in
  the log.
- **Power note (for item 7/DoD):** the DRV2605 is left out of standby while
  awake (~0.5 mA quiescent). Sleep/standby gating lands with item 7's power
  work (`PM_DEVICE` suspend already exists in the driver).

## 7. SK6812 glow chain: order, color, duty  _(PR item 6)_
Rendering is the repo-local `orbit,glow` engine (`modules/orbit/src/glow.c`)
on the stock Zephyr `worldsemi,ws2812-spi` driver (SPIM2, MOSI-only on D6).
Tune **with the TPU sleeve fitted** — the lenses diffuse and dim the dots.
- [ ] **Observe:** at boot, all 8 dots come up faint amber (idle scene).
  **Expected:** color reads as warm amber (#FFB457 family) through the
  sleeve, no green/blue tint. If tinted, the strip's color order is off —
  fix `color-mapping` on the `ws2812@0` node (SK6812 variants exist in GRB
  and RGB).
- [ ] **Observe:** touch CS4 (west-most zone). **Expected:** the WEST-most
  dot (LED0) flashes brighter for ~180 ms. Walk all zones: CS4→0, CS5→1,
  CS6→2, CS1→3, CS3→4, CS2→5, CS7→6, CS8→7. If the pattern is mirrored, the
  chain was routed east→west — reverse `zone-leds` on the `glow` node.
- [ ] **Observe:** idle duty and flash brightness through the sleeve.
  **Tune:** `idle-brightness` (8%) and `flash-brightness` (30%) on the
  `glow` node. **The 30% is a spec cap on battery, not a starting point** —
  go down, not up. All-LED current at 30% ≈ tens of mA; check the power
  budget (§12) before raising anything.
- [ ] **Observe:** leave the device untouched for the ZMK idle timeout
  (30 s default). **Expected:** glow fades to fully off (quiet-desk
  identity + battery). Touch → idle scene returns instantly.
- [ ] **Observe:** after deep sleep (30 min) or power-off, ALL LEDs are
  dark. WS2812s latch their last frame — if any dot stays lit in sleep, the
  sleep-blank path failed; check the activity listener log.
- [ ] **Observe:** first LED glitches/flickers at low battery. SK6812 on a
  battery-voltage rail with 3.3 V logic is in-margin per spec §2, but
  marginal near full charge (4.2 V rail wants ≥ 2.9 V data-high). If seen,
  it's the hardware series-resistor/level topic from the spec, not firmware.
- **Note:** the breathe scene exists (`orbit_glow_breathe()`) but nothing
  triggers it until item 7 wires it to proximity wake.

## 8. Wake: IMU wake-on-motion + CAP proximity  _(PR item 7)_
Deep sleep is nRF System OFF; **waking is a full reboot** (expect the boot
glow breathe, then BLE reconnect under it — that's the intended masking).
Wake sources are armed by `orbit,wake` (`modules/orbit/src/wake.c`) on the
way down. All register values are AN4987/datasheet starting points — this
section is the tuning pass.
- [ ] **Observe:** let the device deep-sleep (30 min idle, or shorten
  `CONFIG_ZMK_IDLE_SLEEP_TIMEOUT` for the bench). Nudge the desk vs. pick the
  unit up. **Expected:** desk vibrations do NOT wake it; picking it up does.
  **Tune:** `wake-threshold` on the `wake@6a` node (steps of 31.25 mg at
  2 g full scale; 2 = 62.5 mg). Raise for fewer false wakes.
- [ ] **Observe:** with the unit asleep, bring a hand near the slider edge
  (CS7/CS8 are ganged as the proximity antenna, sleeve fitted).
  **Expected:** approach wakes it before contact. **Tune:**
  `proximity-sensitivity` (0–7) and `proximity-threshold` on `wake@6a`.
  Too sensitive self-wakes from drift — verify it stays asleep overnight.
- [ ] **Observe:** on every wake/boot: glow breathes for ~2 s
  (`breathe-ms`) while BLE reconnects; typing/pointing works as soon as
  reconnect completes. If reconnect routinely outlives the breathe, raise
  `breathe-ms`.
- [ ] **Measure (DoD):** soft-sleep current, target **< 50 µA**. Budget:
  nRF System OFF ~1 µA + IMU low-power 26 Hz ~5 µA + CAP1188 standby
  (dominant term, duty-cycled) + DRV2605/LED quiescents. If over budget the
  knob is the CAP1188 STANDBY_CONFIG cycle time (reg 0x41 — not yet exposed
  in DT; raw default 0x39 ≈ 70 ms cycles) and, if needed, dropping the
  proximity wake entirely (motion-only wake still meets the spec's intent).
- [ ] **Observe:** wake works with the device on USB too (System OFF + USB
  is a corner: charger keeps the rail up — confirm no boot loop).

## 9. BLE profiles + gesture switch  _(PR item 8)_
Gesture: **hold a slider pad (~300 ms) + spin the crown** = step through the
5 BLE profiles; each step ticks the LRA and blinks the profile's index on
LED0–4. **Hold one pad alone for 5 s = `BT_CLR`** (clears the ACTIVE
profile's bond — deliberate friction, see below).
- [ ] **Observe:** pair two hosts on profiles 0/1. Hold CS7 (or CS8), spin
  the crown one detent. **Expected:** haptic tick, one LED of LED0–4 lights
  ~0.9 s showing the new index, HID output moves to the other host within a
  second or two. Spin back — returns.
- [ ] **Observe:** quick slider taps still do volume; the hold must engage
  before the crown affects profiles (base layer keeps the crown on volume).
  **Tune:** `tapping-term-ms` on the `sht` hold-tap in `vessel.keymap`
  (300): shorter = profile layer engages faster but quick volume taps risk
  reading as holds.
- [ ] **Observe:** hold one pad 5 s without spinning. **Expected:** at 5 s
  the active profile's bond clears (host disconnects; profile is ready to
  re-pair). The 5 s is `long-hold-ms` on `slider_chord`
  (`vessel.overlay`) — it is intentionally far above gesture time; if it
  ever fires during normal profile switching, RAISE it (a surprise BT_CLR
  is the worst UX failure this device can produce).
  - Known interaction: the long-hold timer does NOT know about crown spins;
    a 5 s+ hold *while* switching will still fire BT_CLR at 5 s. Bench-check
    whether real usage ever holds that long mid-gesture.
- [ ] **Observe:** profile blinks also fire when the profile changes by any
  other path (e.g. `&bt` bindings added later, or a host-initiated switch) —
  the indicator listens to ZMK's profile event, not the gesture.

## 10. Crown wheel scroll  _(PR item 9)_
The crown is now a true mouse wheel (`&msc` per detent); volume lives on the
slider. The profile layer (§9) still overrides the crown while a slider pad
is held.
- [ ] **Observe:** spin the crown in a scrollable window. **Expected:** one
  wheel step per detent, spin-toward-you = scroll down. If inverted, swap
  `SCRL_DOWN`/`SCRL_UP` on `rot_scroll` in `vessel.keymap` — OR swap
  `a-gpios`/`b-gpios` in the overlay if §2's direction check also failed
  (fix the hardware sense once, not twice).
- [ ] **Observe:** scroll feel vs. detent count. 24 edges/rev = 24 wheel
  ticks/rev. If that reads too fast/slow on-device, the knobs are `steps`
  on the encoder node (§2) or a scaler processor later — capture the feel
  here first.
- [ ] **Observe:** volume still works from slider taps only (CS7 down /
  CS8 up, chord = mute); nothing else emits volume anymore.

## 11. Manufacturing test mode  _(spec §6)_
Flash the **`vessel-testmode-xiao_ble`** CI artifact (a separate uf2 — the
normal build never contains any of this). Open the USB CDC serial console
(it enumerates alongside HID; logs start ~3 s after boot).
- [ ] **Observe:** banner `=== ORBit MANUFACTURING TEST MODE ===`, then:
  - **LED walk** — one LED per second, 0→7, forever. Any dark position =
    that LED or its data-in joint.
  - **Haptic sweep** — one ROM effect per 8-second lap (`HAPTIC effect N`
    in the log). Note the IDs that feel right for §6's per-zone table.
  - **Touch dumps** — every zone press/release logs `TOUCH code=N`.
  - **Trackball** — roll it; per-second `TRACKBALL dx dy` summaries.
  - **IMU** — per-second raw accel; flip the unit and watch z change sign.
  - Crown detents are verified via host scroll (item 9), not the log —
    the encoder is a ZMK sensor, not an input device.
- **Not covered:** speaker tone — audio is Phase-2 scope (spec §5); there is
  no amp path in v1 firmware to exercise. Add a tone step when I2S lands.

<!--
## 12. Power budget                                   — DoD
     (soft-sleep < 50 µA; active < 5 mA avg w/ glow at duty; 30-day standby
      on 450 mAh; survives sleeve on/off without retune — auto-recal on wake)
      Measured via §8's sleep checks + §7's duty tuning; record numbers here.
-->

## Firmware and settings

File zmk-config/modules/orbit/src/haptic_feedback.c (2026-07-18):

/*
 * ORBit haptic feedback glue (spec §4 item 5).
 *
 * Playback goes through the stock Zephyr ti,drv2605 haptics driver: on each
 * mapped EV_KEY press, load the ROM effect into the waveform sequencer and
 * set GO. That path is a handful of 400 kHz I2C register writes on the input
 * dispatch thread — well inside the spec's <10 ms touch-to-haptic budget.
 *
 * Auto-calibration is ours: the driver's public API rejects
 * DRV2605_MODE_AUTO_CAL as a config trigger (drv2605_haptic_config_rom
 * returns -EINVAL), so calibration talks to the same chip directly through
 * its own i2c_dt_spec. Boot flow, per the spec ("auto-cal at boot, persist"):
 *
 *   - stored result in settings ("orbit/lracal")? restore the three cal
 *     registers, switch to closed loop, done — no motor buzz.
 *   - nothing stored? run the chip's auto-cal routine (MODE=0x07 + GO, poll
 *     GO from the system workqueue in 100 ms slices), then persist the
 *     compensation/back-EMF/gain results.
 *
 * The Zephyr driver deliberately forces LRA OPEN loop (CONTROL3 bit 0) so an
 * uncalibrated chip still works. Open loop needs no cal but drives the LRA
 * at a fixed period; closed loop tracks resonance and is what makes an LRA
 * feel crisp. So: cal success/restore => clear the open-loop bit; cal
 * failure/timeout => keep the driver's open-loop fallback and still play
 * effects. Either way `ready` flips on and touches produce feedback.
 */

#define DT_DRV_COMPAT orbit_haptic_feedback

#include <zephyr/kernel.h>
#include <zephyr/device.h>
#include <zephyr/init.h>
#include <zephyr/input/input.h>
#include <zephyr/drivers/i2c.h>
#include <zephyr/drivers/haptics.h>
#include <zephyr/drivers/haptics/drv2605.h>
#include <zephyr/settings/settings.h>
#include <zephyr/sys/atomic.h>
#include <zephyr/logging/log.h>

LOG_MODULE_REGISTER(orbit_haptics, CONFIG_HAPTICS_LOG_LEVEL);

BUILD_ASSERT(DT_NUM_INST_STATUS_OKAY(DT_DRV_COMPAT) == 1,
             "orbit,haptic-feedback supports exactly one instance");

/* DRV2605L registers touched directly for calibration (not exposed by the
 * Zephyr driver). Names per the TI datasheet register map. */
#define HF_REG_STATUS        0x00
#define HF_STATUS_DIAG_FAIL  BIT(3) /* 0 = last diag/cal passed */
#define HF_REG_MODE          0x01
#define HF_MODE_AUTO_CAL     0x07   /* also leaves STANDBY clear */
#define HF_MODE_INT_TRIG     0x00
#define HF_REG_GO            0x0C
#define HF_GO                BIT(0)
#define HF_REG_ACAL_COMP     0x18
#define HF_REG_ACAL_BEMF     0x19
#define HF_REG_FB_CTRL       0x1A
#define HF_FB_BEMF_GAIN      GENMASK(1, 0) /* cal result lands here */
#define HF_REG_CONTROL1      0x1B
#define HF_CTRL1_DRIVE_TIME  GENMASK(4, 0)
#define HF_REG_CONTROL3      0x1D
#define HF_CTRL3_LRA_OPEN_LOOP BIT(0)

#define HF_SETTINGS_KEY      "orbit/lracal"
#define HF_CAL_POLL_MS       100
#define HF_CAL_POLL_MAX      20 /* 2 s >> the ~1 s worst-case LRA cal */

#define HF_LEN DT_INST_PROP_LEN(0, codes)

enum hf_phase {
    HF_PHASE_START,
    HF_PHASE_POLL,
};

static const uint16_t hf_codes[HF_LEN] = DT_INST_PROP(0, codes);
static const uint16_t hf_effects[HF_LEN] = DT_INST_PROP(0, effects);
BUILD_ASSERT(DT_INST_PROP_LEN(0, codes) == DT_INST_PROP_LEN(0, effects),
             "codes and effects must be the same length");

static const struct device *const hf_haptics = DEVICE_DT_GET(DT_INST_PHANDLE(0, haptics));
static const struct i2c_dt_spec hf_chip = I2C_DT_SPEC_GET(DT_INST_PHANDLE(0, haptics));

static struct {
    struct k_work_delayable cal_work;
    int64_t last_fire[HF_LEN];
    enum hf_phase phase;
    int polls;
    bool have_saved;
    uint8_t saved[3]; /* ACAL_COMP, ACAL_BEMF, FB_CTRL(BEMF_GAIN bits) */
    atomic_t ready;
} hf_data;

/* --- settings: restore persisted cal results ---------------------------- */

static int hf_settings_set(const char *name, size_t len, settings_read_cb read_cb,
                           void *cb_arg) {
    const char *next;

    if (settings_name_steq(name, "lracal", &next) && !next) {
        if (len != sizeof(hf_data.saved)) {
            return -EINVAL;
        }
        if (read_cb(cb_arg, hf_data.saved, sizeof(hf_data.saved)) < 0) {
            return -EIO;
        }
        hf_data.have_saved = true;
        return 0;
    }

    return -ENOENT;
}

SETTINGS_STATIC_HANDLER_DEFINE(orbit, "orbit", NULL, hf_settings_set, NULL, NULL);

/* --- boot-time calibration state machine (system workqueue) ------------- */

static void hf_cal_apply(const uint8_t cal[3]) {
    i2c_reg_write_byte_dt(&hf_chip, HF_REG_ACAL_COMP, cal[0]);
    i2c_reg_write_byte_dt(&hf_chip, HF_REG_ACAL_BEMF, cal[1]);
    i2c_reg_update_byte_dt(&hf_chip, HF_REG_FB_CTRL, HF_FB_BEMF_GAIN,
                           cal[2] & HF_FB_BEMF_GAIN);
    /* Calibrated: closed loop tracks LRA resonance from here on. */
    i2c_reg_update_byte_dt(&hf_chip, HF_REG_CONTROL3, HF_CTRL3_LRA_OPEN_LOOP, 0);
}
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

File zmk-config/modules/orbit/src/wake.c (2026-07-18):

/*
 * ORBit wake sources (spec §4 item 7).
 *
 * ZMK deep sleep is nRF System OFF: everything stops, wake happens only via
 * GPIO SENSE, and waking is a RESET (full reboot). So this module has two
 * halves:
 *
 *  - Going down (ZMK activity SLEEP event, which fires synchronously before
 *    ZMK calls poweroff): program the IMU's wake-on-motion engine and the
 *    CAP1188's cycled standby-proximity mode over I2C, then arm both
 *    interrupt pins as level wakes. The nRF GPIO driver maps level
 *    interrupts onto SENSE, which System OFF honors. Pins are armed LAST —
 *    a level interrupt with no handler would storm if motion happened in
 *    the few ms before poweroff.
 *
 *  - Coming up (any boot, since wake IS a boot): trigger the glow breathe
 *    scene to mask the 1-2 s BLE reconnect (spec: "glow breathe masks BLE
 *    reconnect").
 *
 * The IMU is handled with raw register writes (ST AN4987 wake-on-motion
 * recipe) — no sensor driver, no data path, no runtime cost while awake:
 * the chip sits in its power-down reset state until the way down. Its
 * 3 V3 rail is a GPIO-controlled regulator (P1.08, replicated from the
 * xiao_ble sense variant DTS); System OFF retains GPIO outputs, so the IMU
 * stays powered while watching for motion.
 */

#define DT_DRV_COMPAT orbit_wake

#include <zephyr/kernel.h>
#include <zephyr/device.h>
#include <zephyr/init.h>
#include <zephyr/drivers/i2c.h>
#include <zephyr/drivers/gpio.h>
#include <zephyr/logging/log.h>

#include <zmk/event_manager.h>
#include <zmk/events/activity_state_changed.h>
#include <zmk/activity.h>

#ifdef CONFIG_ORBIT_GLOW
#include <orbit_glow.h>
#endif

LOG_MODULE_REGISTER(orbit_wake, CONFIG_ZMK_LOG_LEVEL);

BUILD_ASSERT(DT_NUM_INST_STATUS_OKAY(DT_DRV_COMPAT) == 1,
             "orbit,wake supports exactly one instance");

/* LSM6DS3TR-C registers (ST AN4987 §5.1 wake-on-motion) */
#define IMU_REG_CTRL1_XL   0x10
#define IMU_CTRL1_26HZ_2G  0x20 /* ODR 26 Hz low-power, FS 2 g */
#define IMU_REG_WAKE_THS   0x5B
#define IMU_REG_WAKE_DUR   0x5C
#define IMU_REG_TAP_CFG    0x58
#define IMU_TAP_CFG_INT_EN 0x80 /* INTERRUPTS_ENABLE */
#define IMU_REG_MD1_CFG    0x5E
#define IMU_MD1_INT1_WU    0x20 /* route wake-up to INT1 */

/* CAP1188 standby registers (datasheet §6.9-6.13) */
#define CAP_REG_MAIN       0x00
#define CAP_MAIN_STBY      BIT(5)
#define CAP_REG_STBY_CHAN  0x40
#define CAP_STBY_CS7_CS8   0xC0 /* gang the slider pads as proximity antenna */
#define CAP_REG_STBY_SENS  0x42
#define CAP_REG_STBY_THR   0x43

static const struct i2c_dt_spec wake_imu = I2C_DT_SPEC_INST_GET(0);
static const struct i2c_dt_spec wake_cap = I2C_DT_SPEC_GET(DT_INST_PHANDLE(0, touch));
static const struct gpio_dt_spec wake_imu_int =
    GPIO_DT_SPEC_INST_GET(0, imu_int_gpios);
static const struct gpio_dt_spec wake_cap_alert =
    GPIO_DT_SPEC_GET(DT_INST_PHANDLE(0, touch), int_gpios);

static void wake_arm(void) {
    int ret;

    /* IMU wake-on-motion. Each write logged only on failure — this path
     * runs once, right before poweroff. */
    ret = i2c_reg_write_byte_dt(&wake_imu, IMU_REG_CTRL1_XL, IMU_CTRL1_26HZ_2G);
    ret |= i2c_reg_write_byte_dt(&wake_imu, IMU_REG_WAKE_DUR, 0x00);
    ret |= i2c_reg_write_byte_dt(&wake_imu, IMU_REG_WAKE_THS,
                                 DT_INST_PROP(0, wake_threshold));
    ret |= i2c_reg_write_byte_dt(&wake_imu, IMU_REG_TAP_CFG, IMU_TAP_CFG_INT_EN);
    ret |= i2c_reg_write_byte_dt(&wake_imu, IMU_REG_MD1_CFG, IMU_MD1_INT1_WU);
    if (ret != 0) {
        LOG_WRN("IMU wake-on-motion config failed — motion wake unavailable");
    }

    /* CAP1188 standby proximity on the ganged slider pads. */
    ret = i2c_reg_write_byte_dt(&wake_cap, CAP_REG_STBY_CHAN, CAP_STBY_CS7_CS8);
    ret |= i2c_reg_write_byte_dt(&wake_cap, CAP_REG_STBY_SENS,
                                 DT_INST_PROP(0, proximity_sensitivity));
    ret |= i2c_reg_write_byte_dt(&wake_cap, CAP_REG_STBY_THR,
                                 DT_INST_PROP(0, proximity_threshold));
    ret |= i2c_reg_update_byte_dt(&wake_cap, CAP_REG_MAIN, CAP_MAIN_STBY,
                                  CAP_MAIN_STBY);
    if (ret != 0) {
        LOG_WRN("CAP1188 standby config failed — proximity wake unavailable");
    }

    /* Arm the wake pins LAST (see header comment). Level interrupts become
     * nRF SENSE, which is what System OFF wakes on. */
    gpio_pin_configure_dt(&wake_imu_int, GPIO_INPUT);
    gpio_pin_interrupt_configure_dt(&wake_imu_int, GPIO_INT_LEVEL_ACTIVE);
    gpio_pin_interrupt_configure_dt(&wake_cap_alert, GPIO_INT_LEVEL_ACTIVE);
}

static int wake_activity_listener(const zmk_event_t *eh) {
    const struct zmk_activity_state_changed *ev = as_zmk_activity_state_changed(eh);

    if (ev != NULL && ev->state == ZMK_ACTIVITY_SLEEP) {
        wake_arm();
    }

    return ZMK_EV_EVENT_BUBBLE;
}

ZMK_LISTENER(orbit_wake, wake_activity_listener);
ZMK_SUBSCRIPTION(orbit_wake, zmk_activity_state_changed);

#ifdef CONFIG_ORBIT_GLOW
static void wake_breathe_work_fn(struct k_work *work) {
    ARG_UNUSED(work);
    orbit_glow_breathe(DT_INST_PROP(0, breathe_ms));
}

static K_WORK_DELAYABLE_DEFINE(wake_breathe_work, wake_breathe_work_fn);
#endif

static int wake_init(void) {
#ifdef CONFIG_ORBIT_GLOW
    /* Every boot is potentially a proximity/motion wake (System OFF wake =
     * reset); breathe while BLE reconnects. */
    k_work_schedule(&wake_breathe_work, K_MSEC(300));
#endif
    return 0;
}

SYS_INIT(wake_init, APPLICATION, CONFIG_APPLICATION_INIT_PRIORITY);

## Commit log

2026-07-18 item 3: zone map — CS4 back, CS5 fwd, CS6 dictation-hotkey PTT (#8)
    CS4/CS5 -> &mkp MB4/MB5 (standard browser back/forward buttons).
    CS6 -> &kp C_VOICE_COMMAND (HID consumer 0xCF, the dictation/mic key):
    held while touched, since the input processor presses on touch and
    releases on lift — PTT semantics with no custom code. Tuning point
    documented for hosts that don't honor 0xCF (e.g. Win10 -> &kp LG(H)).
    HARDWARE_VALIDATION.md gains §4: back/fwd pass criteria, per-OS PTT
    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
2026-07-18 item 4: slider v1 — CS7/CS8 volume taps, both = mute via chord module (#9)
    CS7 -> vol-down, CS8 -> vol-up (spec offers scroll-or-volume; item 9
    settles it: slider owns volume once the crown takes wheel scroll).
    'Both = mute' can't be done with stock ZMK: combos only exist for kscan
    positions and the touch zones are input events. Adds a repo-local Zephyr
    module (zmk-config/modules/orbit) with orbit,input-processor-chord — an
    input processor ahead of the behaviors map that holds a first pad press
    for timeout-ms (75), rewrites a paired press into one KEY_MUTE
    press/release, and replays quick single taps. Spinlock state machine +
    FIFO injection accounting; worst case degrades to a missed ch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
2026-07-18 item 5: DRV2605L haptics — stock Zephyr driver + auto-cal/persist glue (#10)
    The spec assumed no driver exists; that's true of ZMK but Zephyr 4.1
    ships ti,drv2605 (haptics subsystem), so playback is the stock driver —
    same primary-path philosophy as the cap12xx win in item 2.
    Repo-local glue (orbit,haptic-feedback in modules/orbit) adds what the
    driver lacks:
    - per-zone ROM effects on raw pad contact (<10 ms; input callback on
    the cap1188): sharp click L/R (4), lighter M (5), soft tick back/fwd
    (26), double-tick PTT (10), micro-tick slider (24) — all DT tuning
    points. dedup-ms=90 stops the chord processor's re-injected CS7/CS8
    presses from double-buzzing.
    - LRA auto-cal at boo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
    [haptic_feedback.c]
2026-07-18 item 6: SK6812 glow — amber scenes on stock ws2812-spi (SPIM2) (#11)
    * item 6: SK6812 glow — amber scenes on stock ws2812-spi (SPIM2)
    Not ZMK RGB underglow (whole-strip effects, RGB theatrics): a small
    orbit,glow engine renders the spec's exact scene list on the Zephyr
    led_strip API — low-duty amber idle, per-zone flash on touch (input
    callback on the cap1188), breathe primitive exported for item 7's
    proximity-wake BLE mask, all-off on ZMK idle and sleep. Sleep blanks
    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
2026-07-18 item 7: wake — IMU wake-on-motion + CAP1188 standby proximity (#12)
    Deep sleep is System OFF, so wake = GPIO SENSE and waking = reboot. On
    the ZMK SLEEP event (raised synchronously before poweroff) orbit,wake
    programs both wake engines over I2C and arms the pins as level wakes,
    LAST, to avoid a handler-less level-interrupt storm in the ms before
    poweroff:
    - LSM6DS3TR-C wake-on-motion (AN4987 recipe: 26 Hz low-power, 2 g,
    WAKE_UP_THS from DT, routed to INT1/P0.11). Raw register writes at
    the IMU's bus address — no st,lsm6dsl driver, zero cost while awake.
    - CAP1188 cycled standby with CS7+CS8 ganged as proximity antenna
    (README §5), ALERT as second wake pin. Sensitivity/threshold i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
    [wake.c]
2026-07-18 test mode: manufacturing bench build (spec §6) (#15)
    Separate CI artifact vessel-testmode-xiao_ble: same shield plus
    vessel_testmode.conf via EXTRA_CONF_FILE (own build dir). The normal
    firmware never contains any of this (CONFIG_ORBIT_TEST_MODE default n).
    test_mode.c exercises every v1 subsystem over the ZMK_USB_LOGGING CDC
    console: 1 Hz LED walk through the chain (glow index API), DRV2605 ROM
    effect sweep one effect per lap (also serves as the effect-ID audition
    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
